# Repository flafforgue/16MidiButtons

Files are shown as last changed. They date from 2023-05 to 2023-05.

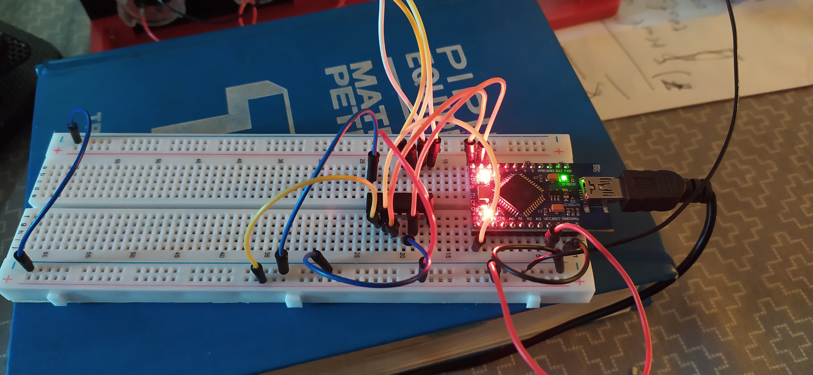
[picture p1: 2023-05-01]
Photos/IMG_20230501_195425.jpg

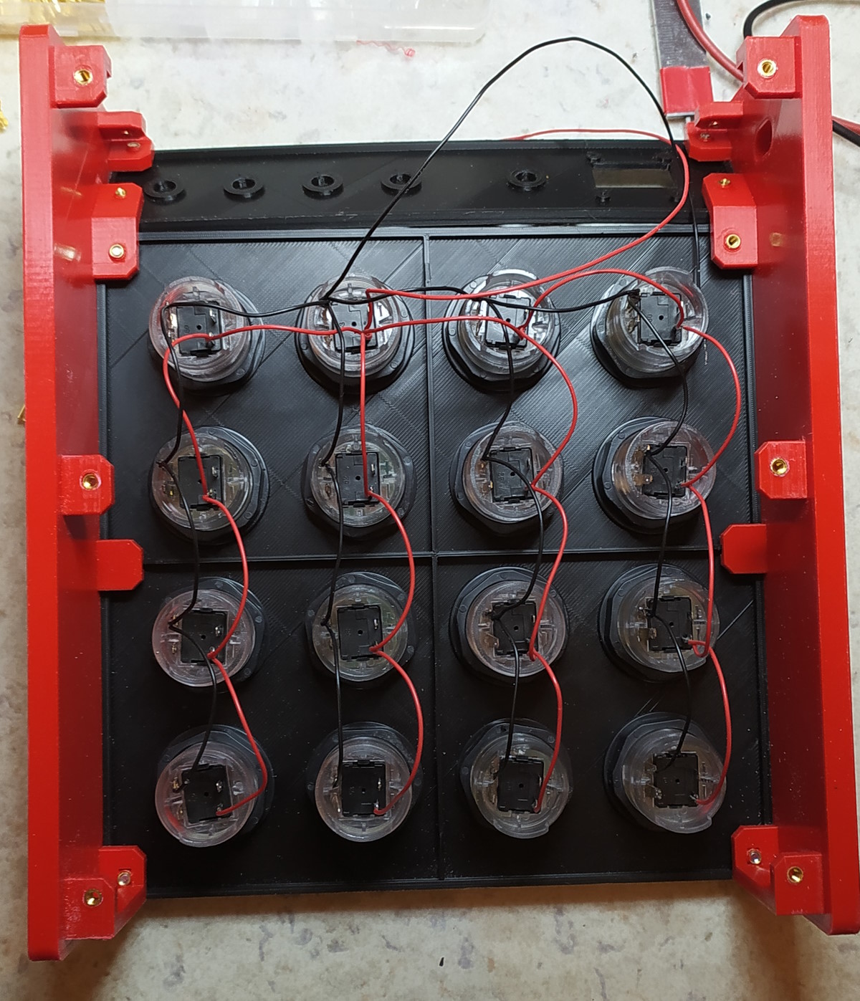
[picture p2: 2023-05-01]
Photos/IMG_20230501_154017.jpg

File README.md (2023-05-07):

# 16MidiButtons
 16 Buttons Midi Controler<br><br>
  16 Buttons<br>
  4 Pots<br>
  1306 Oled 1,3" display<br>
 <br>
 Unsing :<br>
 - Ardunin Micro<br>
 - 2 x 74HC595 for extention of Number Led<br>
 - 2 x 74HC165 for Buttons<br>
 <br> 
 ToDo:<br>
 - realy send Midi message, procedure prepared but empty ;)<br>
 - pots <br>
 - eeprom config save<br>
 - enhanced demo mode<br>
 - Software to Configure on PC<br>
 <br>
 Project Ongoing :<br>
 v0.11 add control switch mode ( see code )<br> 
 V0.10 setup            - ok<br>
 V0.06 Test menus       - ok<br>
 V0.05 test Encoder     - ok<br>
 V0.04 test SSD1306     - ok<br>
 V0.03 test 74HC165 Lib - ok<br>
 V0.02 test 74HC595 Lib - ok<br>
 <br><br>
 Adding Aplication in Lazarys/FreePascal to edit Demo parterns
<br>



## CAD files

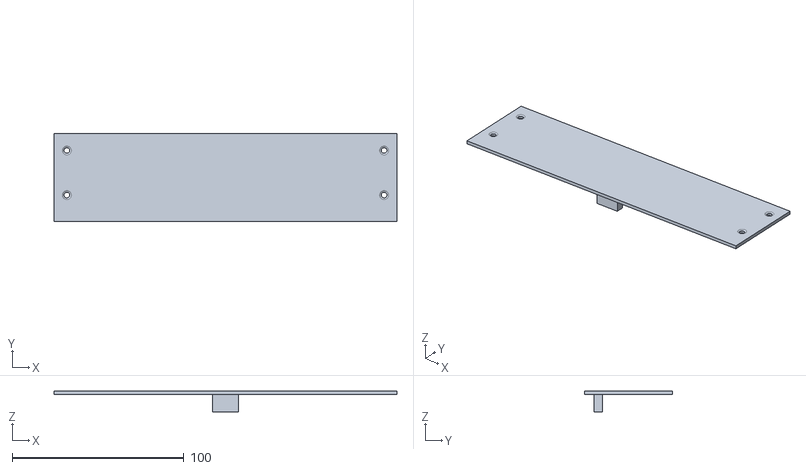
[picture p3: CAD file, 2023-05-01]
Stl/Front-face.STL
200.0 x 51.5 x 12.0

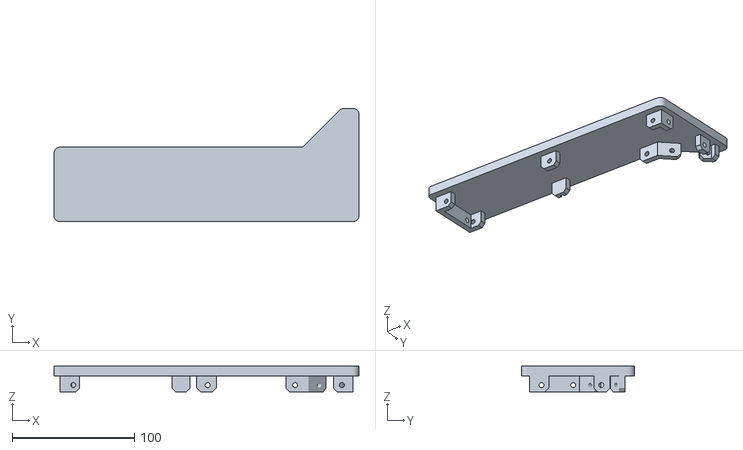
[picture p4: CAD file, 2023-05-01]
Stl/R-side.STL
249.8 x 92.8 x 21.0

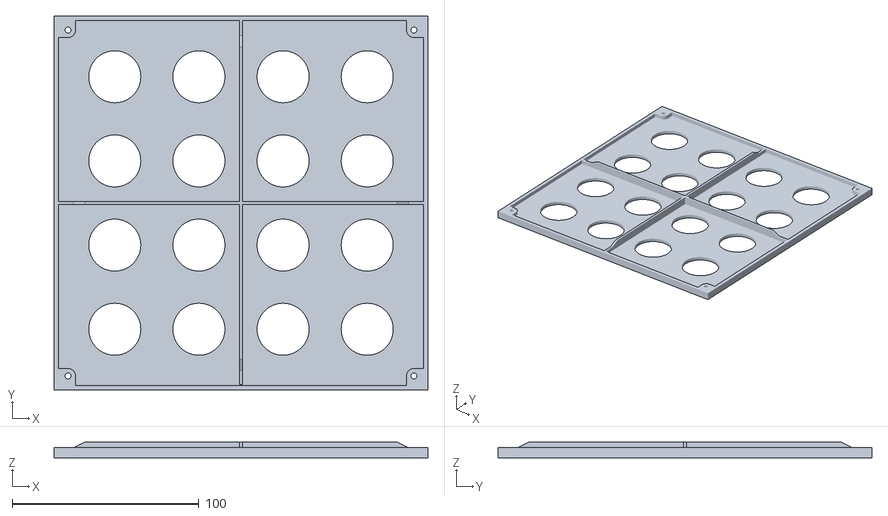
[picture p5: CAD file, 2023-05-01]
Stl/Face-4x4.STL
200.0 x 200.0 x 8.50

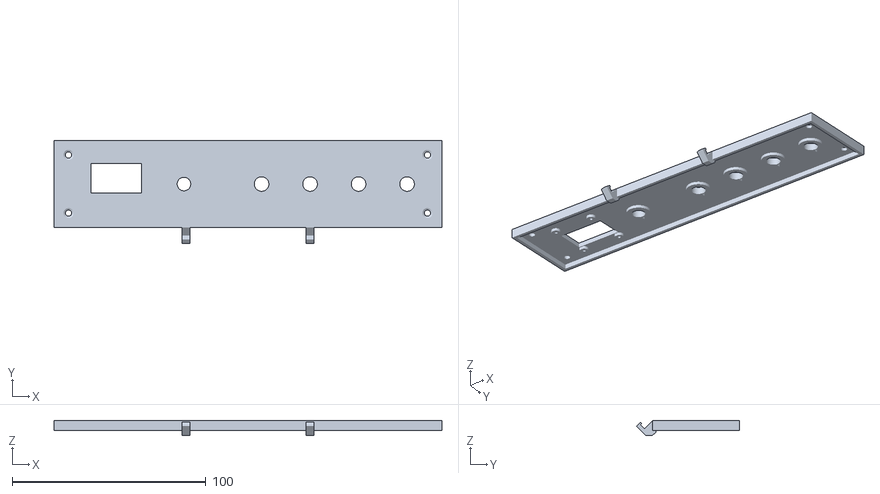
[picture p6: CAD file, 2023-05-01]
Stl/Facade.STL
200.0 x 53.2 x 7.50

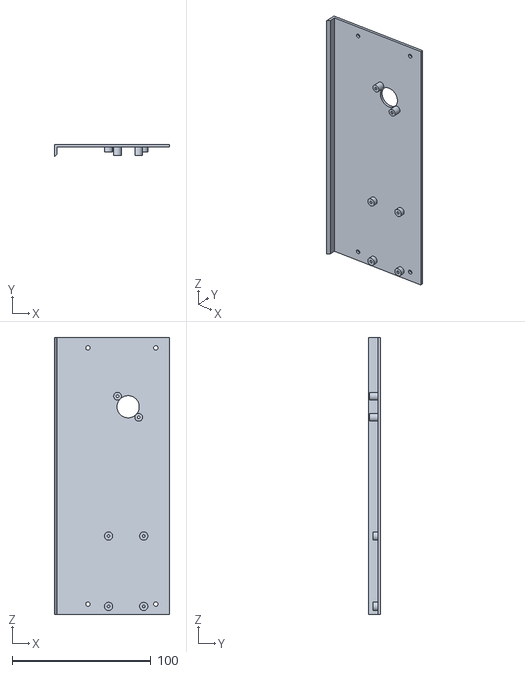
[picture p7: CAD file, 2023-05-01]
Stl/Back-side.STL
83.3 x 9.00 x 200.0

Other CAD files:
Stl/L-side.STL

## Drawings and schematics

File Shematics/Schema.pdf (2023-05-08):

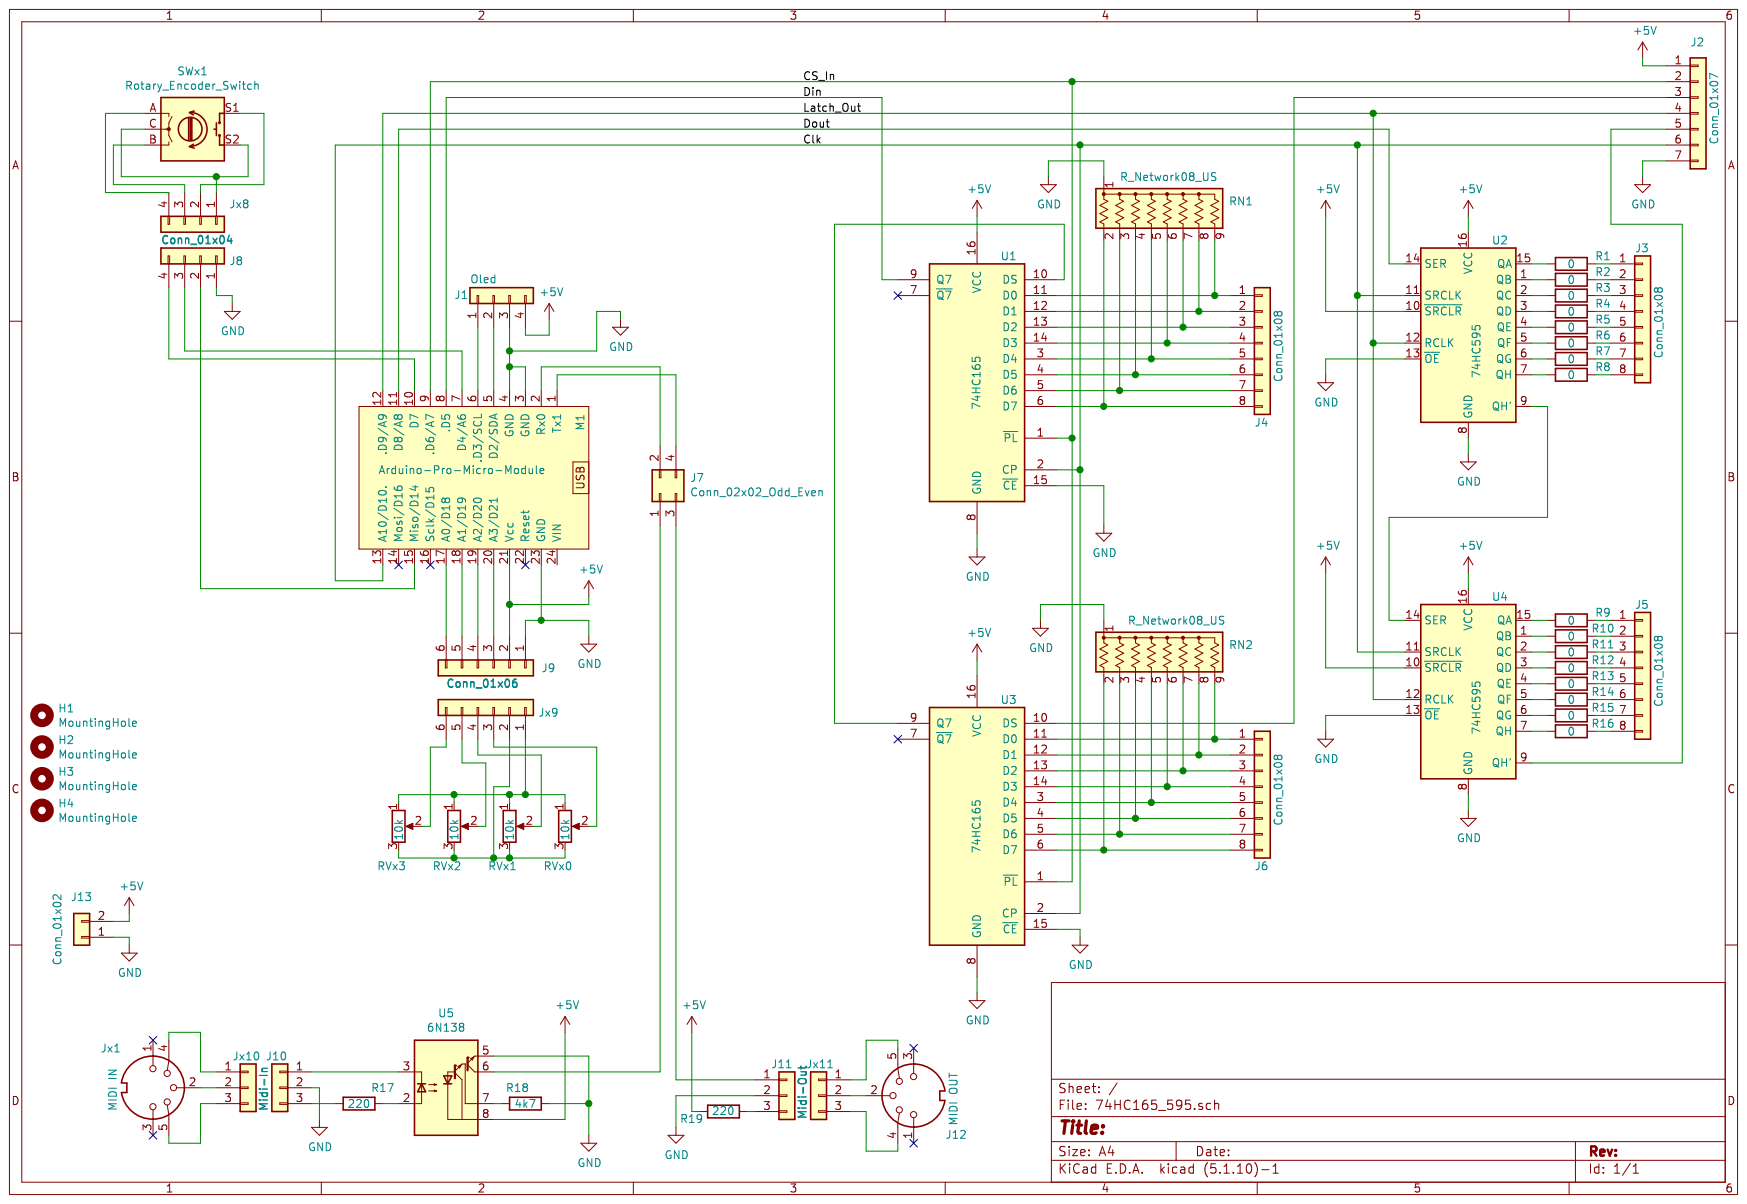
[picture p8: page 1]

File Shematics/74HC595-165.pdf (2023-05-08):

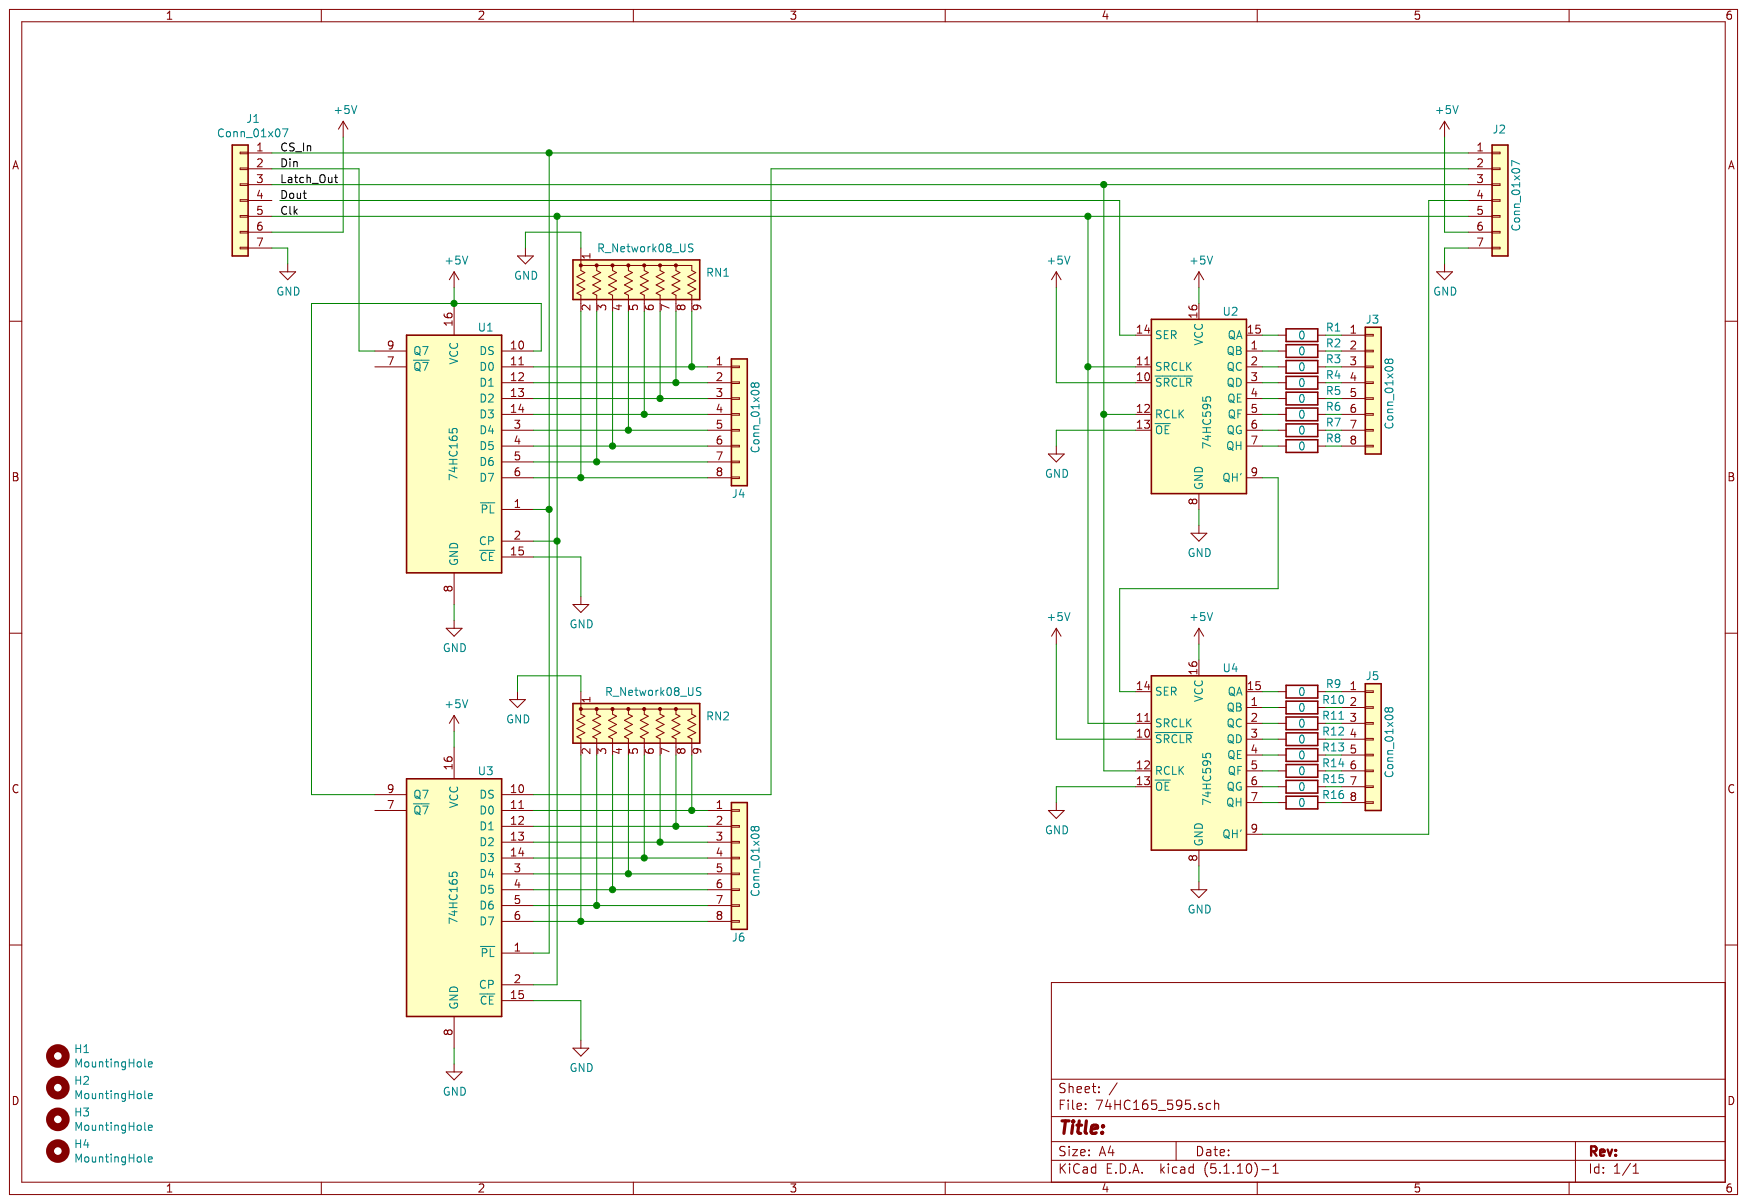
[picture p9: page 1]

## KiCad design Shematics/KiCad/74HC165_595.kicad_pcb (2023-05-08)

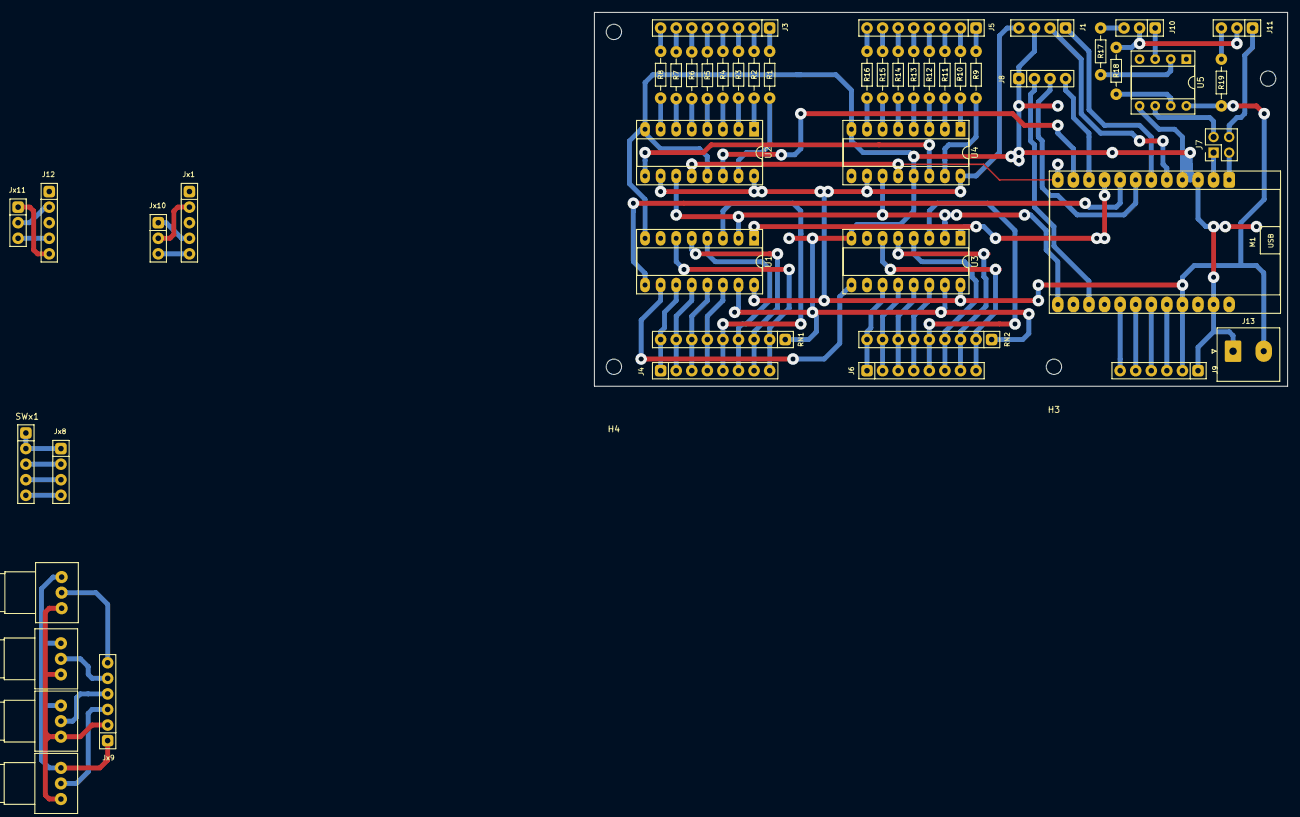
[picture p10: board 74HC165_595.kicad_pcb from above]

Board: 2 copper layers, 113.0 x 61.0 mm, 53 parts (0 on the bottom side), 91 nets.

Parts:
H1, H2, H3, H4: MountingHole; MountingHole_2.5mm
J1: Oled; Con_1x04_P2.54mm
J3, J4, J5, J6: Conn_01x08; Con_1x08_P2.54mm
J7: Conn_02x02_Odd_Even; PinHeader_2x02_P2.54mm_Vertical
J8: Conn_01x04; Con_1x04_P2.54mm
J9: Conn_01x06; Con_1x06_P2.54mm
J10: Midi-In; Con_1x03_P2.54mm
J11: Midi-Out; Con_1x03_P2.54mm
J12: MIDI OUT; Con_1x05_P2.54mm
J13: Conn_01x02; Vis_1x02_P5.00
Jx1: MIDI IN; Con_1x05_P2.54mm
Jx8: Conn_01x04; Con_1x04_P2.54mm
Jx9: Conn_01x06; Con_1x06_P2.54mm
Jx10: Midi-In; Con_1x03_P2.54mm
Jx11: Midi-Out; Con_1x03_P2.54mm
M1: Arduino-Pro-Micro-Module; Arduino-Pro-Micro-DIP-24
R1, R2, R3, R4, R5, R6, R7, R8, R9, R10, R11, R12, R13, R14, R15, R16: 0; Rx
R17, R19: 220; Rx
R18: 4k7; Rx
RN1, RN2: R_Network08_US; Con_1x09_P2.54mm
RVx0, RVx1, RVx2, RVx3: 10k; Pot_APLS_Single
SWx1: Rotary_Encoder_Switch; Encoder
U1, U3: 74HC165; DIP-16_W7.62mm_Socket_LongPads
U2, U4: 74HC595; DIP-16_W7.62mm_Socket_LongPads
U5: 6N138; DIP-8_W7.62mm_Socket

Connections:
+5V: J1.4, J9.2, J13.2, M1.21, R19.1, U1.16, U2.10, U2.16, U3.16, U4.10, U4.16, U5.8
/CS_In: M1.9, U1.1, U3.1
/Clk: M1.13, U1.2, U2.11, U3.2, U4.11
/Din: M1.8, U1.9
/Dout: M1.11, U2.14
/Latch_Out: M1.12, U2.12, U4.12
GND: J1.3, J8.1, J9.1, J10.2, J11.2, J13.1, M1.3, M1.4, M1.23, R18.1, RN1.1, RN2.1, U1.8, U1.15, U2.8, U2.13, U3.8, U3.15, U4.8, U4.13, U5.5
unnamed: J1.1, M1.6
unnamed: J1.2, M1.5
unnamed: J3.1, R1.1
unnamed: J3.2, R2.1
unnamed: J3.3, R3.1
unnamed: J3.4, R4.1
unnamed: J3.5, R5.1
unnamed: J3.6, R6.1
unnamed: J3.7, R7.1
unnamed: J3.8, R8.1
unnamed: J4.1, RN1.9, U1.11
unnamed: J4.2, RN1.8, U1.12
unnamed: J4.3, RN1.7, U1.13
unnamed: J4.4, RN1.6, U1.14
unnamed: J4.5, RN1.5, U1.3
unnamed: J4.6, RN1.4, U1.4
unnamed: J4.7, RN1.3, U1.5
unnamed: J4.8, RN1.2, U1.6
unnamed: J5.1, R9.1
unnamed: J5.2, R10.1
unnamed: J5.3, R11.1
unnamed: J5.4, R12.1
unnamed: J5.5, R13.1
unnamed: J5.6, R14.1
unnamed: J5.7, R15.1
unnamed: J5.8, R16.1
unnamed: J6.1, RN2.9, U3.11
unnamed: J6.2, RN2.8, U3.12
unnamed: J6.3, RN2.7, U3.13
unnamed: J6.4, RN2.6, U3.14
unnamed: J6.5, RN2.5, U3.3
unnamed: J6.6, RN2.4, U3.4
unnamed: J6.7, RN2.3, U3.5
unnamed: J6.8, RN2.2, U3.6
unnamed: J7.1, M1.2
unnamed: J7.2, U5.6
unnamed: J7.3, M1.1
unnamed: J8.2, M1.15
unnamed: J8.3, M1.7
unnamed: J8.4, M1.10
unnamed: J9.3, M1.20
unnamed: J9.4, M1.19
unnamed: J9.5, M1.18
unnamed: J9.6, M1.17
unnamed: J10.1, U5.3
unnamed: J10.3, R17.2
unnamed: J7.4, J11.1
unnamed: J11.3, R19.2
unnamed: J12.2, Jx11.2
unnamed: J12.4, Jx11.3
unnamed: J12.5, Jx11.1
unnamed: Jx1.2, Jx10.2
unnamed: Jx1.4, Jx10.1
unnamed: Jx1.5, Jx10.3
unnamed: Jx8.1, SWx1.C, SWx1.S2
unnamed: Jx8.2, SWx1.S1
unnamed: Jx8.3, SWx1.B
unnamed: Jx8.4, SWx1.A
unnamed: Jx9.1, RVx0.1, RVx1.1, RVx2.1, RVx3.1
unnamed: Jx9.2, RVx0.3, RVx1.3, RVx2.3, RVx3.3
unnamed: Jx9.3, RVx0.2
unnamed: Jx9.4, RVx1.2
unnamed: Jx9.5, RVx2.2
unnamed: Jx9.6, RVx3.2
unnamed: R1.2, U2.15
unnamed: R2.2, U2.1
unnamed: R3.2, U2.2
unnamed: R4.2, U2.3
unnamed: R5.2, U2.4
unnamed: R6.2, U2.5
unnamed: R7.2, U2.6
unnamed: R8.2, U2.7
unnamed: R9.2, U4.15
unnamed: R10.2, U4.1
unnamed: R11.2, U4.2
unnamed: R12.2, U4.3
unnamed: R13.2, U4.4
unnamed: R14.2, U4.5
unnamed: R15.2, U4.6
unnamed: R16.2, U4.7
unnamed: R17.1, U5.2
unnamed: R18.2, U5.7
unnamed: U1.10, U3.9
unnamed: U2.9, U4.14

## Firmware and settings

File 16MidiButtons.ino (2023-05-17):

// ----------------------------------------------------------------------------
//                      16 Buttons Midi Controler
// ----------------------------------------------------------------------------
// Arduino Micro 32U4
//
//
// V 0.12 add pots and visualization during live 
// V 0.11 Setup with Control switch mode
//                   Clrl "Normal" Mode send value when pressing
//                   CtrS "Switch" Mode first press send High value and switch light On 
//                                      second send Low value and Switch light Off
// V 0.10 setup
// V 0.06 Test menus       - ok
// V 0.05 test Encoder     - ok
// V 0.04 test SSD1306     - ok
// V 0.03 test 74HC165 Lib - ok
// V 0.02 test 74HC595 Lib - ok
//
// (C) 2023 under GNU Licence  - F.Lafforgue
// ----------------------------------------------------------------------------

// D0       I2  Rx 
// D1       I3  Tx        Midi out
// D2       I1  SDA       SSD1306
// D3~      I0  SCL       SSD1306
// D4   A6                RotB
// D5~                    DIN165
// D6~  A7                LATCH165
// D7       I6            RotA
// D8   A8                DOUT595
// D9~  A9                LATCH595
// D10~ A10               CLK595 / CLK165
// D14          MISO      RotBTN
// D15          SCLK
// D16          MOSI
// D18  A0                Pot3 
// D19  A1                Pot2
// D20  A2                Pot1
// D21  A3                Pot0

#define CLK595             10
#define LATCH595            9
#define DOUT595             8

#define CLK165             10
#define LATCH165            6
#define DIN165              5

#define SDA                 2
#define SCL                 3

#define ROT_A               7
#define ROT_B               4
#define BTNEncoder         14

#define Pot0               A3
#define Pot1               A2
#define Pot2               A1
#define Pot3               A0

// ----------------------------------------------------------------------------

#include <Wire.h>
#include <EEPROM.h>
#include <Adafruit_GFX.h>
#include <Adafruit_SSD1306.h>

#define OLedWidth         128
#define OLedHight          64
#define OLedReset          -1
#define OLedAdr          0x3C

Adafruit_SSD1306 OLed(OLedWidth, OLedHight, &Wire, OLedReset);

#include "Lib_74HC595.h"
#include "Lib_74HC165.h"
#include "BitsOpperations.h"

// ============================================================================
//                                     Midi
// ============================================================================

#define MSGMask        B11110000
#define CHNMask        B00001111

#define MidiModeNote   B10000000
#define MidiCtrlChange B10110000
#define MidiProgChange B11000000

                        // 16 Butons + 4 Pots
byte ChnMessage[20] = { B10001010, B10001010, B10001010, B10001010,   B10001010, B10001010, B10001010, B10001010, 
                        B10001010, B10001010, B10001010, B10001010,   B10000001, B10000001, B10000001, B10000001,                     
                        B10110000, B10110000, B10110000, B10110000  };
                        
byte ChnData1[20]   = {  51,  49,  57,  55,     41,  43,  45,  44,     
                         47,  48,  50,  46,     36,  38,  37,  42,     
                          7,   1,  12,  13 }; 

byte ChnData2[20]   = { 127, 127, 127, 127 ,   127, 127, 127, 127 , 
                        127, 127, 127, 127 ,   127, 127, 127, 127 ,
                          0,   0,   0,   0 };
                        
byte ChnData2f[20]  = {   0,   0,   0,   0 ,     0,   0,   0,   0 , 
                          0,   0,   0,   0 ,     0,   0,   0,   0 ,
                          0,   0,   0,   0 };
                        
unsigned int Lights =      0; // Status of lights
unsigned int Toggle = 0x0000; // Define which button is in toggle mode

// ----------------------------------------------------------------------------
// Note On     : 1001 cccc  -  0nnn nnnn  -  0vvv vvvv  : c channel 0-16 : n Note 0-127       : v Velocity 0-127
// Note Off    : 1000 cccc  -  0nnn nnnn  -  0vvv vvvv  : c channel 0-16 : n Note 0-127       : v Velocity 0-127
// Prg Change  : 1100 cccc  -  0iii iiii  -  0... ....  : c channel 0-16 : i instrument 0-127 : . unused
// Ctrl Change : 1011 cccc  -  0nnn nnnn  -  0vvv vvvv  : c channel 0-16 : n Controler  0-127 : v value 0-127

// DRUM Kit
// 36  -  Bass Drum 1
// 38  -  Acoustic Snare
// 37  -  Side Stick
// 42  -  Closed Hi-Hat
//
// 47  -  Low-Mid Tom
// 48  -  Hi-Mid Tom
// 50  -  High Tom
// 46  -  Open Hi-Hat
//
// 41  -  Low Floor Tom
// 43  -  High Floor Tom
// 45  -  Low Tom
// 44  -  Pedal Hi-Hat
//
// 51  -  Ride Cymbal 1
// 49  -  Crash Cymbal 1
// 57  -  Crash Symbol 2
// 55  -  Splash Cymbal
//
// 35  -  Acoustic Bass Drum
// 40  -  Electric Snare
// 39  -  Hand Clap
// 60  -  Hi Bongo
// 61  -  Low Bongo

void SendMidiCmd(byte Msg,byte Data1,byte Data2 ) {
}

void SendButtonPress(byte Chn ) {
  byte Msg;

  Msg=ChnMessage[Chn];
  SendMidiCmd(Msg, ChnData1[Chn], ChnData2[Chn] ); 
}

void SendButtonRelease(byte Chn ) {
  byte Msg;

  Msg=ChnMessage[Chn];
  if (( Msg & MSGMask ) == MidiModeNote ) {  // Send Note Off
     Msg = Msg & B11101111; 
  }
  SendMidiCmd(Msg, ChnData1[Chn], ChnData2[Chn] ); 
}

// ----------------------------------------------------------------------------
//                         Rotary Encoder , button & Pots
// ----------------------------------------------------------------------------

#define BTN_NONE           0
#define BTN_ENC            1
#define BTN_ENC_Long       2

#define BTN_LONGDELAY   1000

byte keydown  =    BTN_NONE;
byte key      =    BTN_NONE;
unsigned long      BTNTime;

int  encodermov     = 0;
byte LastBtnPressed = 0;

//#define ENCSOFTFILTER
#define ENCSOFTFILTERDELAY 25

#ifdef ENCSOFTFILTER
unsigned long OEncTime = 0; 

void doEncoder() {
  unsigned long Nt = millis();
  if ( Nt - OEncTime > ENCSOFTFILTERDELAY ) {
    if (digitalRead(ROT_A) == digitalRead(ROT_B)) {
      encodermov = +1;
    } else {
      encodermov = -1;
    } 
    OEncTime=Nt;   
  }
}
#else
void doEncoder() {
  if (digitalRead(ROT_A) == digitalRead(ROT_B)) {
    encodermov = +1;
  } else {
    encodermov = -1;
  } 
}
#endif

void ClearEncoder() {
  cli();
  encodermov=0;
  sei(); 
}

// ----------------------------------------------------------------------------

#define ROUNDPOTS 0  //
#define DIVPOTS   8  // Analogread 0-1023 - values 0-127 

void ReadPots() {
  ChnData2[16]=( analogRead(Pot0) + ROUNDPOTS ) / DIVPOTS;
  ChnData2[17]=( analogRead(Pot1) + ROUNDPOTS ) / DIVPOTS;
  ChnData2[18]=( analogRead(Pot2) + ROUNDPOTS ) / DIVPOTS;
  ChnData2[19]=( analogRead(Pot3) + ROUNDPOTS ) / DIVPOTS;

  for (byte i=16; i<20;i++) {
    if ( ChnData2f[i] != ChnData2[i] ) { 
      ChnData2f[i]=ChnData2[i];
      LastBtnPressed=i;
    }
  }
}

// ----------------------------------------------------------------------------

void ReadBtnState() {
  unsigned long NTime; 
  NTime=millis();
  
  if ( keydown == BTN_NONE ) { // no key waiting 
    if ( digitalRead (BTNEncoder )==LOW ) { BTNTime=NTime;  keydown=BTN_ENC;    }
  } else {                        // key allready down
    if ( NTime - BTNTime > 10 ) { // avoid rebounds
        switch (keydown) {
           case BTN_ENC:
                 if ( digitalRead (BTNEncoder)==HIGH ) { // keypress on release ;)   
                   if ( NTime - BTNTime >= BTN_LONGDELAY )  key = BTN_ENC_Long;                
                   else                                     key = BTN_ENC;
                   keydown=BTN_NONE;
                 }
                 break;
       }       
    }
  }
}

bool keypressed() {
  return ( key != BTN_NONE );
}

byte readkey() {
  byte tmp = key;
  key=BTN_NONE;
  return( tmp);
}

void MyDelay(unsigned int del) {
  unsigned long ot = millis();
  while ( millis()-ot < del ) {
    ReadBtnState();
  } 
}

// =============================================================
//                    eeprom Recal and Save 
// =============================================================

#define PROGSTAMP 3519

#define Adr_Stamp     0
#define Adr_Msg       2
#define Adr_Data1    42
#define Adr_Data2    82
#define Adr_Data2f  122

void SaveToEprom() {
  EEPROM.put(Adr_Stamp, (int) PROGSTAMP);
  EEPROM.put(Adr_Msg   ,ChnMessage );                     
  EEPROM.put(Adr_Data1 ,ChnData1   );
  EEPROM.put(Adr_Data2 ,ChnData2   );                     
  EEPROM.put(Adr_Data2f,ChnData2f  );
}

void InitFromEprom () {
  int temp;
  EEPROM.get(Adr_Stamp, temp);
  if ( temp == (int) PROGSTAMP ) {       // Stamp found , we can assume eerom contain Valid Datas 
    EEPROM.get(Adr_Msg   ,ChnMessage );                     
    EEPROM.get(Adr_Data1 ,ChnData1   );
    EEPROM.get(Adr_Data2 ,ChnData2   );                     
    EEPROM.get(Adr_Data2f,ChnData2f  );
  } else {                    // Stamp not found , Values need to be initialized
    SaveToEprom(); 
  }
}

// ============================================================================
//                           M E N U    &    D I S P L A Y
// ============================================================================

#define L1                0
#define L2               16
#define L3               32
#define L4               48
#define Lmargin           4

void TitleMenu(String str) {
  OLed.clearDisplay();
  OLed.setTextSize(2);
  OLed.setTextColor(SSD1306_WHITE);
  OLed.setCursor(Lmargin, L1);
  OLed.println(str); 
}

void OLedprint2 ( int value ) {
   if (( value ) < 10 ) { OLed.print(F(" ")); }    // finaly not using sprintf , use more size
   OLed.print(value);
}

void OLedprint4 ( int value ) {
   if (( value ) < 1000 ) { OLed.print(F(" ")); }  // finaly not using sprintf , use more size
   if (( value ) <  100 ) { OLed.print(F(" ")); }   
   if (( value ) <   10 ) { OLed.print(F(" ")); }
   OLed.print(value);
}

// ============================================================================
//                                    Mode Live
// ============================================================================

unsigned int BtnStatus  = 1;
unsigned int oBtnStatus = 0;

void DoLive() {
  boolean       LetRunning = true;
  unsigned long omillis    = 0;  
  unsigned long amillis    = 0;  
  unsigned long zmillis    = 0; 
  unsigned int  BtnChange;

  while ( LetRunning ) {
    ReadBtnState();
    if ( readkey() == BTN_ENC ) {  // if Select Pressed exit
      LetRunning=false;
    }

    if ( millis() - amillis > 5 ) {
      BtnStatus=L165ReadOneWord( );
      amillis=millis();
    }

    if ( BtnStatus != oBtnStatus ) {
      BtnChange= oBtnStatus ^ BtnStatus; // get button changed
      if ( BtnChange > 0 ) {
        for (byte i=0;i<16;i++) {
          unsigned int tmp = BtnChange & ( 1 << i ) ; // Btn change status
          unsigned int prs = BtnStatus & ( 1 << i ) ; // Btn pressed
          unsigned int tgl = Toggle    & ( 1 << i ) ; // Toggle mode
          if ( tmp != 0 ) {
            if ( prs > 0 ) {                   // Btn Pressed
              LastBtnPressed=i;
              SendButtonPress(i);
              if ( tgl > 0 ) {
                Lights = Lights ^ prs;         // Toggle mode , so first press light , second switch off  
              } else {
                Lights = Lights | ( 1 << i );  // Not in toggle mode press switch on light
              }
            } else {                           // Bnt Released 
              SendButtonRelease(i);
              if ( tgl == 0 ) {
                Lights = Lights & ~( 1 << i ); // Not in toggle mode release switch off light
              }
            }
          }
        }
      }  
      L595SendOneWord(Lights);
      oBtnStatus=BtnStatus;
    }
   
     if ( millis() - zmillis > 250 ) {     // Refresh pots every 250 us
      zmillis = millis();
      ChnData2[16]=( analogRead(Pot0) + ROUNDPOTS ) / DIVPOTS;
      ChnData2[17]=( analogRead(Pot1) + ROUNDPOTS ) / DIVPOTS;
      ChnData2[18]=( analogRead(Pot2) + ROUNDPOTS ) / DIVPOTS;
      ChnData2[19]=( analogRead(Pot3) + ROUNDPOTS ) / DIVPOTS;
      for (byte i=16; i<20;i++) {
        if ( ChnData2f[i] != ChnData2[i] ) { 
          ChnData2f[i]=ChnData2[i];
          SendButtonPress(i);
          LastBtnPressed=i;
        }
      }      
    }
       
    if ( millis() - omillis > 300 ) {    // Refresh Display every 300 us
      TitleMenu(F("Live"));
      OLed.setCursor( 4, L2);  OLed.print(F("Chanl")); 
      OLed.setCursor(68, L2);  OLedprint4(ChnMessage[LastBtnPressed] & CHNMask);
      OLed.setCursor(68, L3);  OLedprint4(ChnData1[LastBtnPressed]);
      OLed.setCursor(68, L4);  OLedprint4(ChnData2[LastBtnPressed]);
      
      switch ( ChnMessage[LastBtnPressed] & MSGMask ) {
        case MidiModeNote  :
             OLed.setCursor( 4, L3);  OLed.print(F("Note"));            
             OLed.setCursor( 4, L4);  OLed.print(F("Vel"));             
             break;
        case MidiCtrlChange:            
             OLed.setCursor( 4, L3);  OLed.print(F("Ctrl"));          
             OLed.setCursor( 4, L4);  OLed.print(F("Val"));                         
             break;  
        case MidiProgChange:
             OLed.setCursor( 4, L3);  OLed.print(F("Prog"));          
             break;
      }

      OLed.display();
      omillis = millis();
    }
  }

  ClearEncoder();
}

// ----------------------------------------------------------------------------
//                                   S E T U P
// ----------------------------------------------------------------------------

void DoConfig() {
  boolean       LetRunning = true;
  unsigned long omillis    = 0;  
  byte          Edt        = 0;
  unsigned int  msg;
  
  while ( LetRunning ) {
    ReadBtnState();
    switch ( readkey() ) {
      case BTN_ENC:  
         Edt++;
         if ( Edt > 3) { Edt=0; }
         break; 
      case BTN_ENC_Long:   
         LetRunning=false;
         break;     
    }

    ReadPots();
    if ( LastBtnPressed>15) {
      L595SendOneWord(0);
    }
    BtnStatus=L165ReadOneWord( );
    if ( BtnStatus != oBtnStatus ) {
      oBtnStatus=BtnStatus;
      for (byte i=0;i<16;i++)  {
        if ( ( BtnStatus >> i ) & 1 == 1 ) {
          LastBtnPressed=i; 
          L595SendOneWord(BtnStatus);
        }
      }
    }
  
    if (encodermov != 0 ) {
      switch ( Edt ) {
         case 0:  // Channel number
            ChnMessage[LastBtnPressed] = ( ChnMessage[LastBtnPressed] & MSGMask ) | ((( ChnMessage[LastBtnPressed] & CHNMask ) + encodermov) & CHNMask );
            break;    
         case 1:  // change Mode
            if ( BtnStatus < 16 ) {
              msg = ( ChnMessage[LastBtnPressed] & MSGMask );
              if ( msg == MidiModeNote ) { msg = MidiCtrlChange;  }
              else if ( msg == MidiProgChange ) { msg = MidiModeNote;  }
              else {
                if ( (unsigned int)(Toggle & ( (unsigned int)( 1 << LastBtnPressed ) )) > 0 ) {
                  msg = MidiProgChange;
                  Toggle = Toggle & ( ~ (unsigned int)( 1 << LastBtnPressed ) ); 
                } else {
                  Toggle = Toggle | ( (unsigned int)( 1 << LastBtnPressed ) );
                  msg = MidiCtrlChange;
                }
              }
              ChnMessage[LastBtnPressed] = msg | ( ChnMessage[LastBtnPressed] & CHNMask );
            }
            break;               
         case 2:  // change channel
            ChnData1[LastBtnPressed] = ( ChnData1[LastBtnPressed] + encodermov ) & B01111111;
            break; 
         case 3:  // change data2
            if ( BtnStatus < 16 ) {
              ChnData2[LastBtnPressed] = ( ChnData2[LastBtnPressed] + encodermov ) & B01111111;
            }
            break;                
         case 4:  // change data2f ( min value )
            ChnData2f[LastBtnPressed] = ( ChnData2f[LastBtnPressed] + encodermov ) & B01111111;
            break;                
      }
      cli();
      encodermov=0;
      sei();
    }
    
    if ( millis() - omillis > 150 ) { // Refresh Display every 150 us
      TitleMenu(F("Bt "));  

      switch(Edt) {
        case 0 : OLed.fillRect(64, L1,  63, 16, SSD1306_WHITE); // Channel
                 break;
        case 1 : OLed.fillRect( 0, L2,  63, 16, SSD1306_WHITE); // Mode
                 break;         
        case 2 : OLed.fillRect(64, L2,  63, 16, SSD1306_WHITE); // Note
                 break;         
        case 3 : OLed.fillRect(64, L3,  63, 16, SSD1306_WHITE); // Value / Value on
                 break;        
        case 4 : OLed.fillRect( 0, L3,  63, 16, SSD1306_WHITE); // Value off 
                 break;                     
      }                       
      OLed.setTextColor(SSD1306_INVERSE);
      
      OLed.setCursor(36, L1);OLedprint2(LastBtnPressed);
      OLed.setCursor(68, L1);OLed.print(F("Ch "));  OLedprint2(ChnMessage[LastBtnPressed] & CHNMask);
      
//      OLed.setCursor(68, L2); OLedprint2( ChnMessage[LastBtnPressed] & CHNMask );  // chn
//      unsigned int Tg = ( Toggle    & ( 1 << LastBtnPressed ) );
      switch ( ChnMessage[LastBtnPressed] & MSGMask ) {
        case MidiModeNote  :
             OLed.setCursor( 4, L2);  OLed.print(F("Note"));
             OLed.setCursor(68, L2);  OLedprint4(ChnData1[LastBtnPressed]);
             OLed.setCursor( 4, L3);  OLed.print(F("Vel"));
             OLed.setCursor(68, L3);  OLedprint4(ChnData2[LastBtnPressed]);
             break;
        case MidiCtrlChange:            
             OLed.setCursor(68, L2);  OLedprint4(ChnData1[LastBtnPressed]);       
             OLed.setCursor(68, L3);  OLedprint4(ChnData2[LastBtnPressed]);
             if ( (unsigned int)(Toggle & ( (unsigned int)( 1 << LastBtnPressed ) )) > 0 ) { 
               OLed.setCursor( 4, L2);  OLed.print(F("CtrS"));
               OLed.setCursor( 4, L3);  OLed.print(ChnData2f[LastBtnPressed]);
             } else {
               OLed.setCursor( 4, L2);  OLed.print(F("Ctrl"));            
               OLed.setCursor( 4, L3);  OLed.print(F("Val"));
             }             
             break;  
        case MidiProgChange:
             OLed.setCursor( 4, L2);  OLed.print(F("Prog"));
             OLed.setCursor(68, L2);  OLedprint4(ChnData1[LastBtnPressed]);          
             break;
      }
      
      OLed.display();
      omillis = millis();
    }
  }

  L595SendOneWord(0);
  ClearEncoder();  
}

// ----------------------------------------------------------------------------
//                                     D E M O
// ----------------------------------------------------------------------------

int Tempo = 150;

#define NbDemo 13
 unsigned int TabDemo[NbDemo] = {     0,    15,   240,  3840,
                                  61440,     0, 61440, 65280,
                                  65520, 65535, 28662,  1632,
                                      0 };

void PlayPatern(byte NbSteps, unsigned int Tab[] ) {
  for (byte i=0;i<NbSteps;i++)  {
    L595SendOneWord(Tab[i]);
    ReadBtnState();
    MyDelay(Tempo);
  }
}

void DoDemo() {
  boolean       LetRunning = true;
  unsigned long omillis    = 0;  
    
  while ( LetRunning ) {
    ReadBtnState();
    if ( readkey() == BTN_ENC ) {     // if Select Pressed exit
      LetRunning=false;
    }

    PlayPatern(NbDemo,TabDemo);

    if ( millis() - omillis > 150 ) { // Refresh Display every 150 us
      TitleMenu(F("Demo"));
      OLed.display();
      omillis = millis();
    }
  }
  ClearEncoder();  
}

// ============================================================================
//                          I N I T I A L I Z A T I O N
// ============================================================================

void setup() {
  Serial.begin(115200);

  pinMode(ROT_A      , INPUT_PULLUP);
  pinMode(ROT_B      , INPUT_PULLUP);
  pinMode(BTNEncoder , INPUT_PULLUP);
  
  L595Init();
  L165Init();

  if(!OLed.begin(SSD1306_SWITCHCAPVCC, OLedAdr)) {
    Serial.println(F("SSD1306 Error"));
  } else {
    Serial.println(F("SSD1306 Initialized"));
  }
  OLed.display();  // display adafruit logo

  attachInterrupt(digitalPinToInterrupt(ROT_A), doEncoder, CHANGE ); 
  
  delay(1000);  
  PlayPatern(NbDemo,TabDemo);
  delay(1000);
  ClearEncoder();  
}

// ============================================================================
//                             M A I N    L O O P
// ============================================================================

int menu  = 0;
int omenu = 2;

void loop() {

  if (encodermov != 0 ) {
    cli();
    menu+=encodermov;
    encodermov=0;
    sei();
    if ( menu > 2 ) { menu=0; }
    if ( menu < 0 ) { menu=2; }
  }

  if ( menu != omenu ) {
    OLed.clearDisplay();
    OLed.setTextSize(2);
    OLed.fillRect(0, menu*16, 127, 16, SSD1306_WHITE);
    OLed.setTextColor(SSD1306_INVERSE);
    OLed.setCursor(4, L1);  OLed.print(F("Live"));
    OLed.setCursor(4, L2);  OLed.print(F("Setup"));
    OLed.setCursor(4, L3);  OLed.print(F("Demo"));
    OLed.display();
    omenu=menu;
  }

  ReadBtnState();
  if ( keypressed() ) {
    byte k = readkey();
    if ( k == BTN_ENC ) {
      switch ( menu ) {
        case 0: DoLive();
                break;     
        case 1: DoConfig(); 
                break;
        case 2: DoDemo();
                break;                                       
      }
    }
    omenu=menu+1;  // to force redraw 
  }    
}

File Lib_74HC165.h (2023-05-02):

// ----------------------------------------------------------------------------
//                       74 HC 165 Library
// ----------------------------------------------------------------------------
//
// V 0.01 
//
// (C) 2023 under GNU Licence  - F.Lafforgue
// ----------------------------------------------------------------------------

#ifndef SN74HC165_H

#define SN74HC165_H
#include "Arduino.h"

#ifndef CLK165
  #define CLK165        10
  #define LATCH165       6
  #define DIN165         5
#endif

#define MSBFIRST165
//#define LSBFIRST165


void L165Init() {
  pinMode(CLK165       , OUTPUT );
  pinMode(LATCH165     , OUTPUT );	
  pinMode(DIN165       , INPUT );

  digitalWrite(CLK165  , LOW );
  digitalWrite(LATCH165, LOW );  
}

byte L165ReadOneByte() {
  byte temp=0;
  
  digitalWrite(LATCH165,HIGH);
  for ( byte i=0; i<8; i++ ) {
	// MSBFIRST
	temp = temp | ( digitalRead(DIN165) << ( 7-i) );
    // LSBFIRST
    // temp = temp | ( digitalRead(DIN165) << i );

	digitalWrite(CLK165  , HIGH ); // Pulse
	digitalWrite(CLK165  , LOW );
  }
  digitalWrite(LATCH165,LOW);
  return temp;
}

unsigned int L165ReadOneWord( ) {
  byte temp0=0;
  byte temp1=0;
  unsigned int temp=0;
  
  digitalWrite(LATCH165,HIGH);
  for ( byte i=0; i<8; i++ ) {
    // MSBFIRST
    temp0 = temp0 | ( digitalRead(DIN165) << ( 7-i) );
    digitalWrite(CLK165  , HIGH ); // Pulse
    digitalWrite(CLK165  , LOW );
  }
  for ( byte i=0; i<8; i++ ) {
    // MSBFIRST
    temp1 = temp1 | ( digitalRead(DIN165) << ( 7-i) );
    digitalWrite(CLK165  , HIGH ); // Pulse
    digitalWrite(CLK165  , LOW );
  }
  
  digitalWrite(LATCH165,LOW);
  return temp0 | ( temp1 << 8 );
}

#endif
